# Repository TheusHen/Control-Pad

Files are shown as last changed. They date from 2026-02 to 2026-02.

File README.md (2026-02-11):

# Control Pad – Industrial USB Switch Console

A multi-input industrial-style USB control console featuring 15 physical switches, dual USB-C and triple USB-A inputs.
Designed to convert real electrical states into digital USB logic signals, inspired by cockpit and control room panels.

The Control Pad combines mechanical robustness with clean PCB design, delivering a physical command interface for software control, automation, streaming, simulation, and experimental hardware interaction.

---

## 3D Assembly

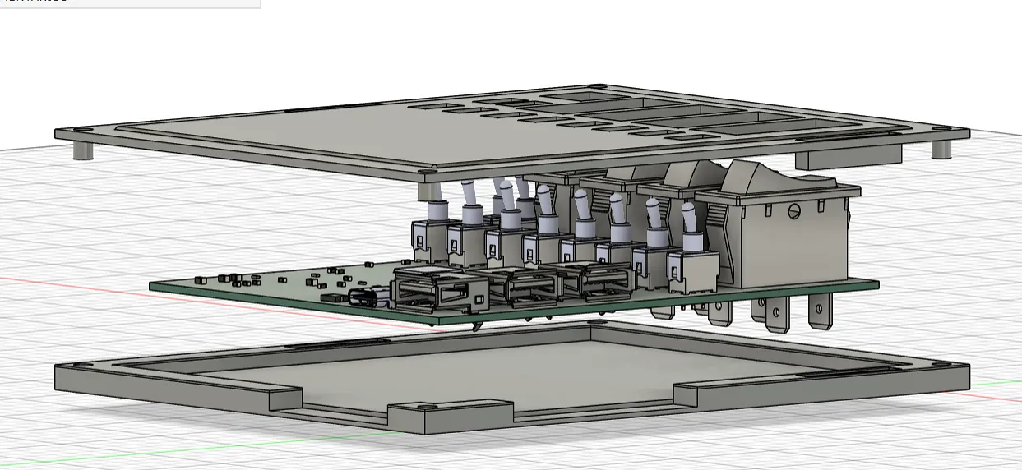
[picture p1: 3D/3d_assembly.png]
Assembly 1

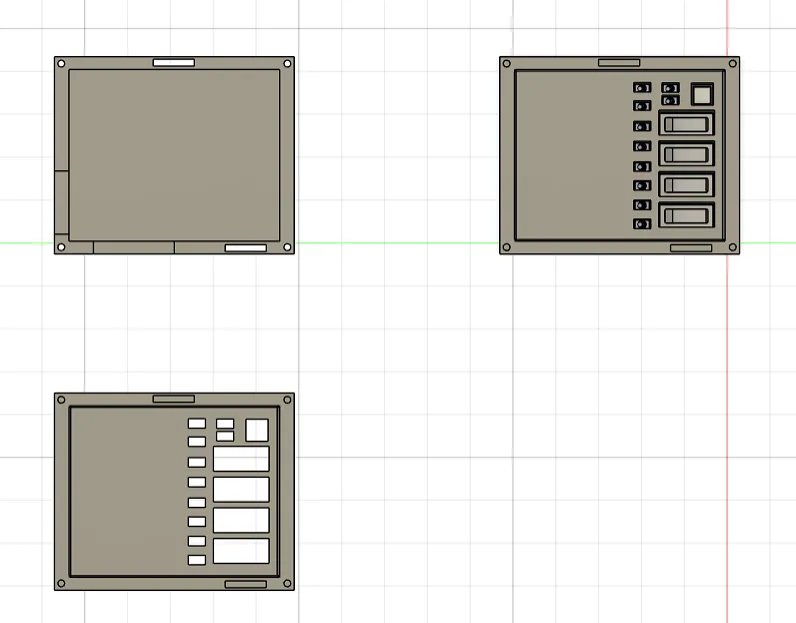
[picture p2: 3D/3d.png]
Assembly 2


---

## Schematic

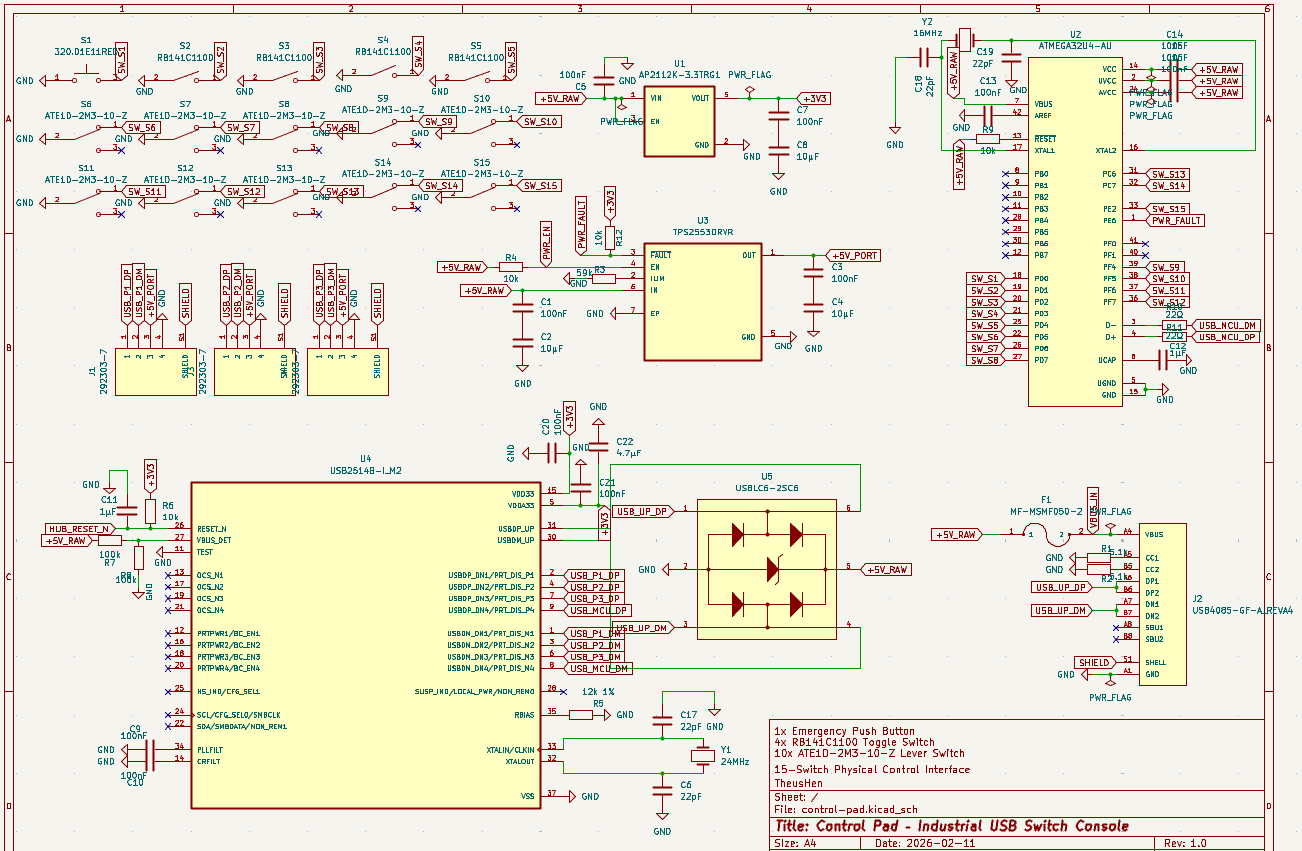
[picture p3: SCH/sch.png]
Schematic


---

## PCB

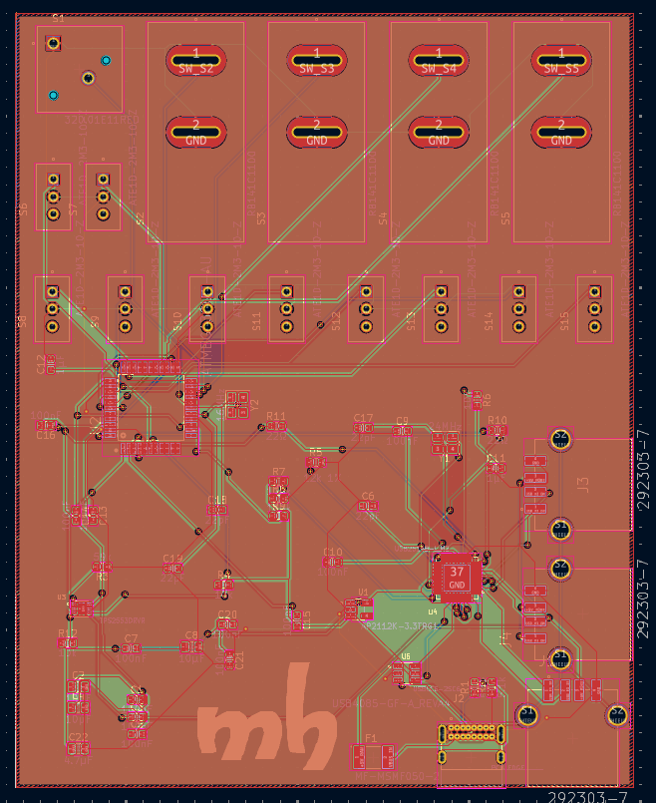
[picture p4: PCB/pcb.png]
PCB


---

## 3D PCB

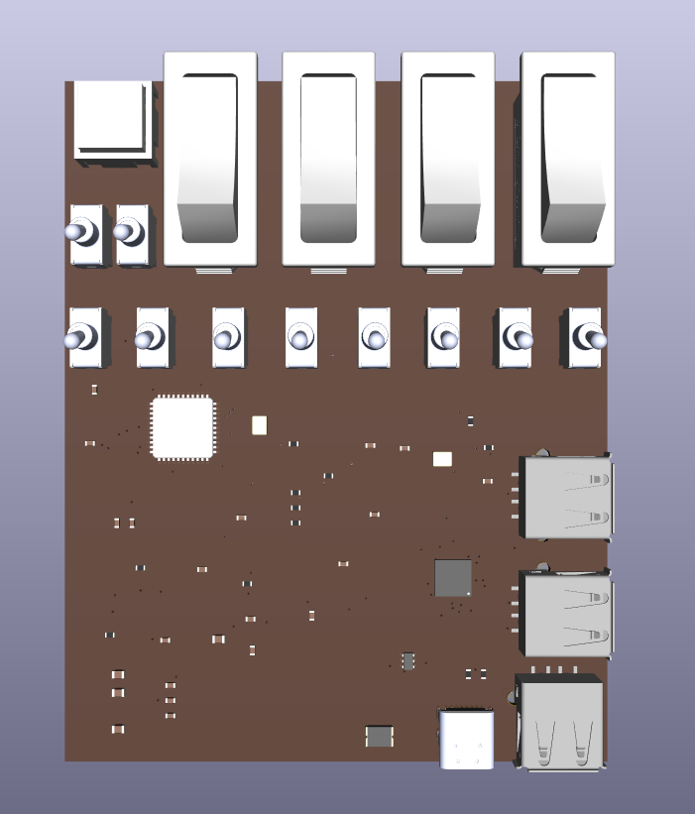
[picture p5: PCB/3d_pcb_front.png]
3D_PCB Front

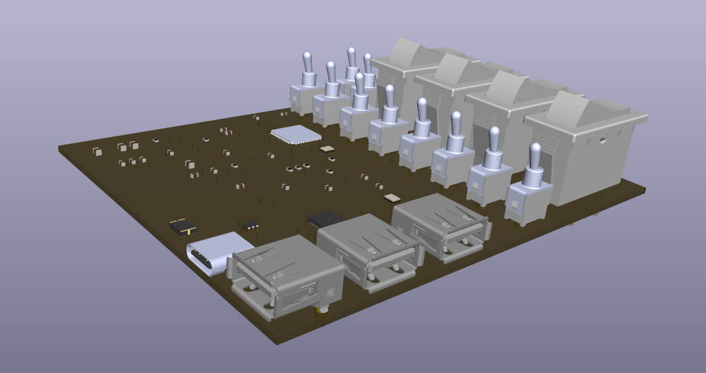
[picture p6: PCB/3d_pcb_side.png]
3D_PCB Side


---

## Case Fit

3D_CASE

---

# Overview

The Control Pad is a 15-switch physical interface composed of:

* 1x Emergency Push Button (Primary Action Trigger)
* 4x RB141C1100 Toggle Switches
* 10x ATE1D-2M3-10-Z Lever Switches
* 2x USB-C Inputs
* 3x USB-A Inputs

The system detects electrical state transitions and converts them into USB logic signals for computer interaction.

Designed with:

* KiCad 9
* 4-layer PCB stackup
* Industrial-style layout
* 3D printed enclosure

---

# Features

* 15 physical control inputs
* Dedicated emergency trigger button
* Multi-USB input architecture
* Electrical-to-digital state conversion
* 4-layer PCB for signal integrity
* Custom 3D case design
* Fully open hardware

---

# Technical Specifications

* PCB: 4 Layers
* Surface Finish: (HASL / ENIG – update accordingly)
* Power via USB
* Digital signal processing via MCU firmware
* Designed for stable mechanical mounting

---

# Firmware

Firmware implemented in `firmware/` (C++, PlatformIO, ATmega32U4):

* HID Gamepad output for 15 inputs
* Debounced input scanning
* Mapping:
  * `EMERGENCY = 0`
  * `RB1..RB4 = 1..4`
  * `TOGGLE1..TOGGLE10 = 5..14`

## `studio/`

Implemented with Tauri + TypeScript (Windows-focused):

* Captures HID directly
* Per-input configurable actions (`none`, `key combo`, `command`)
* Profile system with active profile switching
* Profile hotkeys: `Ctrl + Alt + Shift + 1..9`
* Tray icon workflow and background behavior
* Autostart support and local config persistence on PC

---

# Notes

* All switches are panel-mounted and aligned to the enclosure geometry.
* The emergency button is intended for high-priority actions.
* Lever switches are positioned for ergonomic interaction.

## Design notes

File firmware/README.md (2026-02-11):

# Control Pad Firmware (ATmega32U4, C++)

This firmware sends all 15 physical controls as **Gamepad HID buttons**.

## Input IDs

- `0` = `EMERGENCY`
- `1..4` = `RB1..RB4`
- `5..14` = `TOGGLE1..TOGGLE10`

## Stack

- Framework: Arduino (C++)
- Target: ATmega32U4 (`leonardo` profile in PlatformIO)
- HID: `MHeironimus/Joystick` (Gamepad type)

## Build / Flash

```powershell
cd firmware
pio run
pio run -t upload
```

## Tests

```powershell
cd firmware
pio test -e native
```

## Notes

- Debounce is implemented in firmware with integrator logic (`12` scan counts at `1 ms` scan by default).
- Inputs use `INPUT_PULLUP` and are treated as **active-low**.
- Pin mapping is centralized in `src/pins.cpp` (`kInputPins`) for quick adjustment to PCB routing.
- Code is split by responsibility:
  - `include/control_pad/config.hpp`
  - `include/control_pad/pins.hpp`
  - `include/control_pad/debounce.hpp`
  - `src/app.cpp`
  - `src/pins.cpp`
  - `src/debounce.cpp`

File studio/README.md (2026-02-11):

# Control Pad Studio

Windows-focused desktop app built with Tauri + TypeScript.

## Features

- Direct HID capture from the Control Pad device
- Per-input action mapping:
  - `none`
  - `key_combo` (ex.: `Ctrl+Alt+1`)
  - `command` (program + args)
- Multiple profiles
- Active profile switching with global hotkeys:
  - `Ctrl + Alt + Shift + 1..9`
- Tray icon behavior and hide-to-tray on close
- Autostart support
- Config persistence on PC (`%APPDATA%\ControlPadStudio\studio-config.json`)

## Development

```powershell
cd studio
npm install
npm test
npm run build
```

For full Tauri desktop run, Rust toolchain is required.

## Notes

- This app is currently targeted to Windows usage.
- HID listener runs in backend (Rust) and keeps working while window is hidden.

## Project Structure

- `frontend/`
  - `main.ts` (entry)
  - `controller.ts` (app orchestration and handlers)
  - `ui.ts` (render and DOM helpers)
  - `state.ts` (runtime state + config helpers)
  - `types.ts`, `constants.ts`
- `src-tauri/src/`
  - `lib.rs` (Tauri bootstrap)
  - `commands.rs` (Tauri commands)
  - `hid_listener.rs` (HID capture loop)
  - `actions.rs` (action execution)
  - `config_store.rs` (config persistence)
  - `models.rs`, `state.rs`

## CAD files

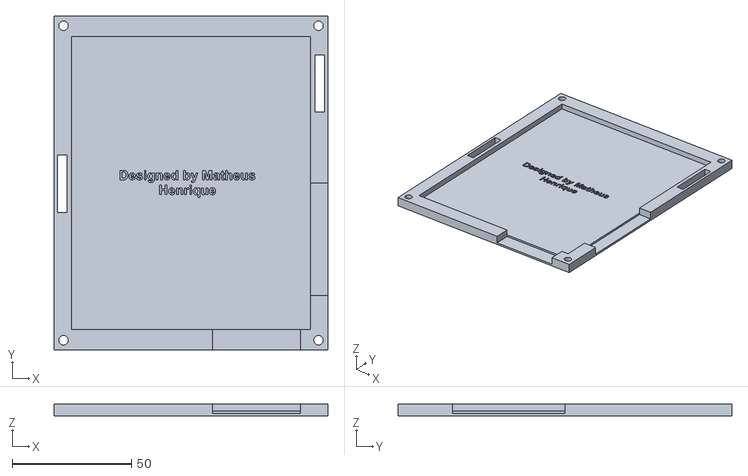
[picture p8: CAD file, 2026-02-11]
3D_STL/Control Pad_bottom.stl
115.0 x 140.0 x 5.00

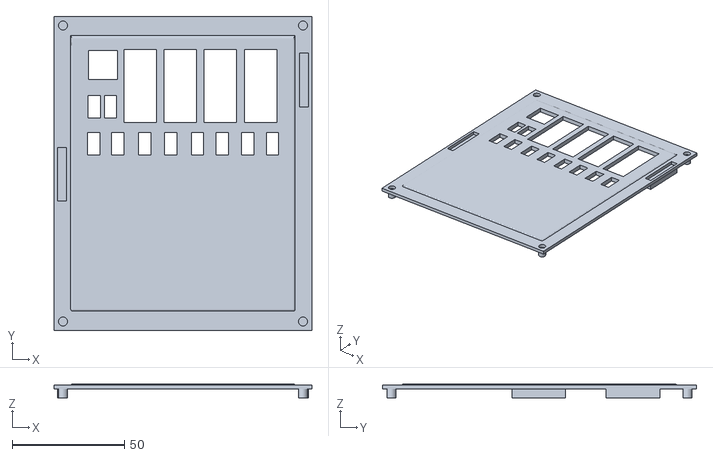
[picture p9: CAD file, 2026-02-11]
3D_STL/Control Pad_top.stl
115.0 x 140.0 x 6.40

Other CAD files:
3D/Control Pad.f3z

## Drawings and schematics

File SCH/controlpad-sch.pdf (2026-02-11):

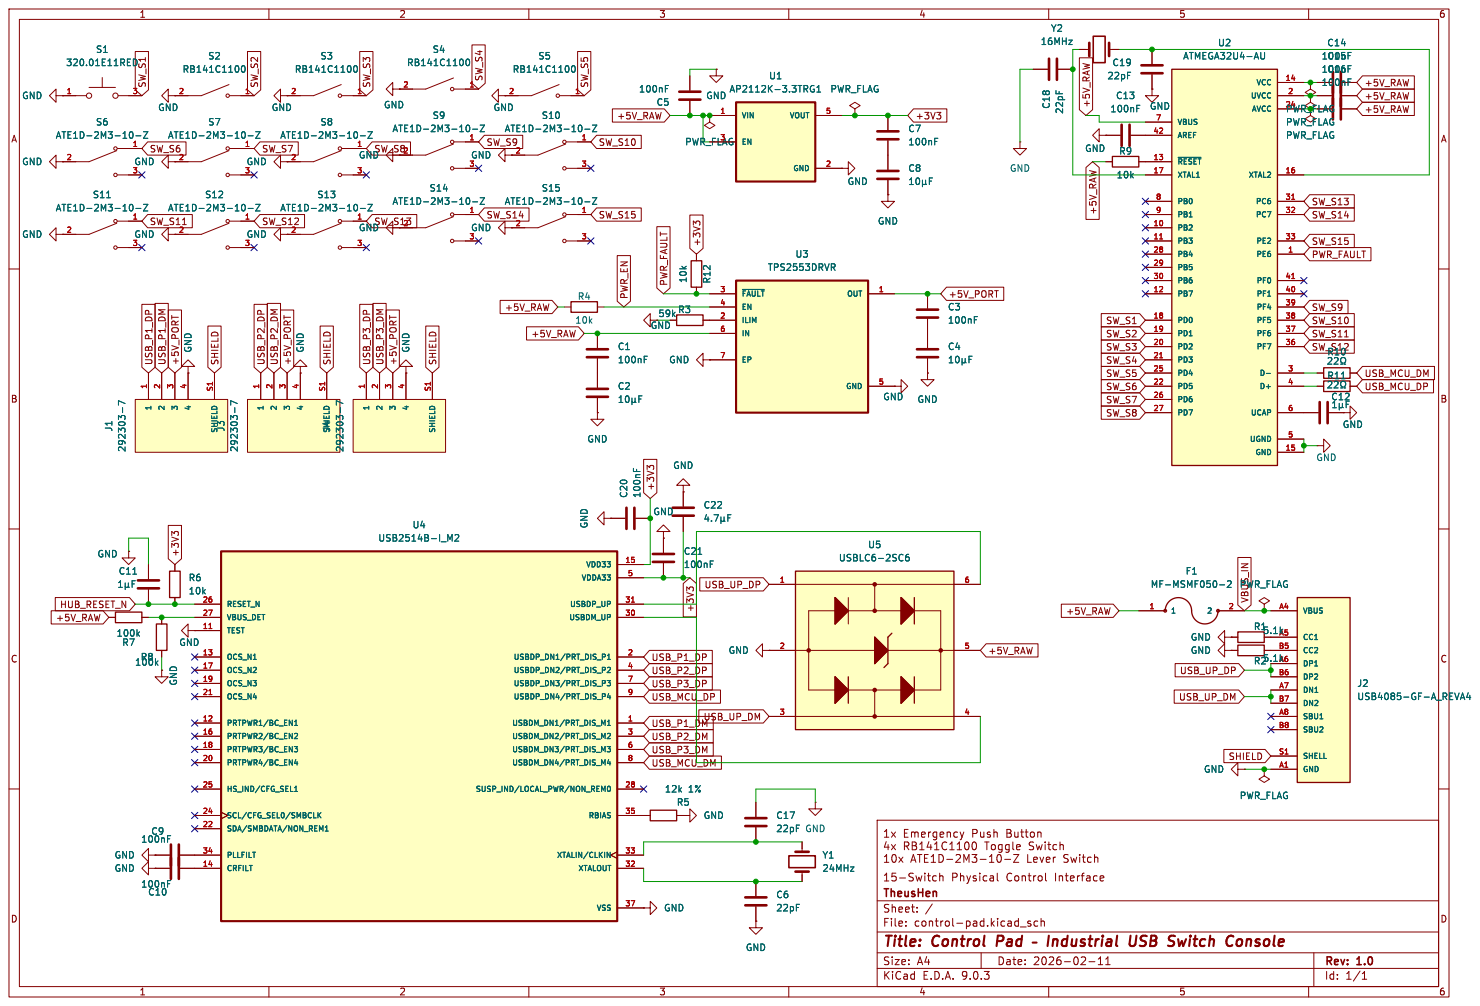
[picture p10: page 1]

File: control-pad.kicad_sch Sheet: / TheusHen

Id: 1/1 Title: Control Pad þÿ Industrial USB Switch Console

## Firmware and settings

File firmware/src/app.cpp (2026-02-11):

#include "control_pad/app.hpp"

#include <Joystick.h>

#include "control_pad/config.hpp"
#include "control_pad/debounce.hpp"
#include "control_pad/pins.hpp"

namespace control_pad {
namespace {

DebouncedInput g_inputs[kInputCount];

Joystick_ g_gamepad(
    JOYSTICK_DEFAULT_REPORT_ID,
    JOYSTICK_TYPE_GAMEPAD,
    kInputCount,
    0,     // hat switches
    false, // x axis
    false, // y axis
    false, // z axis
    false, // rx axis
    false, // ry axis
    false, // rz axis
    false, // rudder
    false, // throttle
    false, // accelerator
    false, // brake
    false  // steering
);

uint32_t g_next_scan_ms = 0;
uint32_t g_last_report_ms = 0;

void debugPrintChange(uint8_t input_id, bool pressed) {
  if (!kEnableSerialDebug) {
    return;
  }

  Serial.print(F("ID "));
  Serial.print(input_id);
  Serial.print(F(" -> "));
  Serial.println(pressed ? F("PRESSED") : F("RELEASED"));
}

void initializeInputs() {
  for (uint8_t i = 0; i < kInputCount; ++i) {
    configureInputPullup(kInputPins[i]);
  }
}

void initializeState() {
  for (uint8_t i = 0; i < kInputCount; ++i) {
    const bool pressed = readPressedActiveLow(kInputPins[i]);
    g_inputs[i].stable_pressed = pressed;
    g_inputs[i].integrator = pressed ? kDebounceCounts : 0;
    g_gamepad.setButton(i, pressed);
  }
  g_gamepad.sendState();
  g_last_report_ms = millis();
}

bool scanInputs() {
  bool changed = false;

  for (uint8_t i = 0; i < kInputCount; ++i) {
    const bool sample_pressed = readPressedActiveLow(kInputPins[i]);
    if (!updateDebounce(g_inputs[i], sample_pressed)) {
      continue;
    }

    g_gamepad.setButton(i, g_inputs[i].stable_pressed);
    debugPrintChange(i, g_inputs[i].stable_pressed);
    changed = true;
  }

  return changed;
}

void sendReportIfNeeded(bool changed, uint32_t now) {
  if (!changed) {
    return;
  }

  if (kMinReportIntervalMs == 0 || (now - g_last_report_ms) >= kMinReportIntervalMs) {
    g_gamepad.sendState();
    g_last_report_ms = now;
  }
}

} // namespace

void setup() {
  if (kEnableSerialDebug) {
    Serial.begin(kSerialBaud);
    delay(50);
    Serial.println(F("Control Pad firmware start"));
  }

  // Manual report mode. We call sendState() only when state changes.
  g_gamepad.begin(false);

  initializeInputs();
  initializeState();
  g_next_scan_ms = millis() + kScanIntervalMs;
}

void loop() {
  const uint32_t now = millis();
  if ((int32_t)(now - g_next_scan_ms) < 0) {
    return;
  }

  g_next_scan_ms += kScanIntervalMs;
  sendReportIfNeeded(scanInputs(), now);
}

} // namespace control_pad

// Arduino core entry points.
void setup() { control_pad::setup(); }

void loop() { control_pad::loop(); }

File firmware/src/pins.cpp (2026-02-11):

#include "control_pad/pins.hpp"

#include <avr/io.h>

#if !defined(__AVR_ATmega32U4__)
#warning "Control Pad pin map is designed for ATmega32U4."
#endif

namespace control_pad {

void configureInputPullup(const AvrPin &pin) {
  *pin.ddr &= ~pin.bit_mask;
  *pin.port |= pin.bit_mask;
}

bool readPressedActiveLow(const AvrPin &pin) { return ((*pin.pin) & pin.bit_mask) == 0; }

// Mapping from schematic:
// SW_S1..SW_S8  -> PD0..PD7
// SW_S9..SW_S12 -> PF4..PF7
// SW_S13..SW_S14 -> PC6..PC7
// SW_S15 -> PE2
const AvrPin kInputPins[kInputCount] = {
    {&PIND, &DDRD, &PORTD, _BV(0)}, // SW_S1  -> EMERGENCY
    {&PIND, &DDRD, &PORTD, _BV(1)}, // SW_S2  -> RB1
    {&PIND, &DDRD, &PORTD, _BV(2)}, // SW_S3  -> RB2
    {&PIND, &DDRD, &PORTD, _BV(3)}, // SW_S4  -> RB3
    {&PIND, &DDRD, &PORTD, _BV(4)}, // SW_S5  -> RB4
    {&PIND, &DDRD, &PORTD, _BV(5)}, // SW_S6  -> TOGGLE1
    {&PIND, &DDRD, &PORTD, _BV(6)}, // SW_S7  -> TOGGLE2
    {&PIND, &DDRD, &PORTD, _BV(7)}, // SW_S8  -> TOGGLE3
    {&PINF, &DDRF, &PORTF, _BV(4)}, // SW_S9  -> TOGGLE4
    {&PINF, &DDRF, &PORTF, _BV(5)}, // SW_S10 -> TOGGLE5
    {&PINF, &DDRF, &PORTF, _BV(6)}, // SW_S11 -> TOGGLE6
    {&PINF, &DDRF, &PORTF, _BV(7)}, // SW_S12 -> TOGGLE7
    {&PINC, &DDRC, &PORTC, _BV(6)}, // SW_S13 -> TOGGLE8
    {&PINC, &DDRC, &PORTC, _BV(7)}, // SW_S14 -> TOGGLE9
    {&PINE, &DDRE, &PORTE, _BV(2)}  // SW_S15 -> TOGGLE10 (HWB)
};

} // namespace control_pad

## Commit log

2026-02-07 Initialized KiCAD Project
    [control-pad.kicad_pcb, control-pad.kicad_sch]
2026-02-11 Reorganize hardware project structure and add manufacturing assets
    [Control Pad.f3z, Control Pad_bottom.stl, Control Pad_top.stl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]
2026-02-11 Fix Joystick constructor args for firmware build
    [app.cpp]
2026-02-11 Fix missing Arduino setup/loop symbols in firmware build
    [app.cpp]
2026-02-11 Add explicit exit flow and close confirmation for tray mode
2026-02-11 Fix global shortcut ACL and fallback unregister flow
